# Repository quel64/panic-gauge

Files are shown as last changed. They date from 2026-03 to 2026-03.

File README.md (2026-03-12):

# VIX Fear Gauge Terminal
> **Project Stasis (Tier 2)** | A real-time market volatility monitor.

This project is a dedicated hardware terminal that fetches the **VIX (Volatility Index)** via the Alpha Vantage API and renders a dynamic intraday graph on a 3.2" TFT display.
I made this project because having the value of this index I think is of great importance right now because of the recent conflicts of the world. This terminal allows you to have this "fear gauge" always close to you so if it spikes you know that something big is happening.




## Features
- **Live Tracking:** Real-time updates via Wi-Fi.
- **Dynamic Scaling:** The graph auto-zooms to show movement even during low volatility.
- **Dual Themes:** Swap between Dark Mode and Light Mode with a physical button.
- **Timeframe Toggle:** Switch between 1-minute and 5-minute data resolution.

## Setup & Configuration
1. **Library Install:** Install `TFT_eSPI` and `ArduinoJson` in your Arduino IDE.
2. **Driver Config:** - Navigate to `Arduino/libraries/TFT_eSPI/User_Setup.h`.
   - Ensure the driver is set to `#define ILI9341_DRIVER`.
   - Set pins: `MOSI: 4`, `SCLK: 5`, `CS: 7`, `DC: 6`, `RST: 10`.
3. **API Key:** Get a free key from [Alpha Vantage](https://www.alphavantage.co/support/#api-key).
4. **Firmware:** Open `firmware_vixterminal.ino`, enter your Wi-Fi credentials and API Key, then upload.

## Button Usage
- **Top Button (GPIO 2):** Swaps the data timeframe (1min / 5min).
- **Bottom Button (GPIO 3):** Toggles between Dark and Light UI themes.

## Design
The case features a minimalist **20-degree slant** optimized for desktop viewing. It is 3D-printed in two parts (main body and bottom plate) and requires no screws—the internal components have to be secured via some small drops of adhesive on the backplate.

# Wiring diagram
Component -	Pin	- Connects To

Power -	USB 5V - AMS1117 VIN

Power	- AMS1117 VOUT - ESP32-C3 3.3V & TFT VCC

Power	- GND	- All Common Grounds

Display	- SCK	- ESP32 GPIO 5

Display	- SDI	- ESP32 GPIO 4

Display	- CS	- ESP32 GPIO 7

Display	- DC	- ESP32 GPIO 6

Display	- RST	- ESP32 GPIO 10

Button - 1 - ESP32 GPIO 2 (Timeframe)

Button - 2 - ESP32 GPIO 3 (Theme)

# Project Bill of Materials (BOM)
| Component | Description | Price | Source |
| :--- | :--- | :--- | :--- |
| **ESP32-C3** | Main MCU (SuperMini) | $2.04 | [Link](https://shorturl.at/nSwdf) |
| **3.2" SPI TFT LCD** | ILI9341 Display | $9.32 | [Link](https://shorturl.at/U1MPf) |
| **Solderable Perfboard** | 4x6cm Prototyping Board | $2.19 | [Link](https://shorturl.at/WMAwI) |
| **AMS1117-3.3V** | Voltage Regulator | $1.26 | [Link](https://shorturl.at/bQWA9) |
| **Rubber Feet** | For bottom of the case | $1.71 | [Link](https://shorturl.at/vf0jC) |
| **10uF Capacitors** | Power stabilization | $2.63 | [Link](https://shorturl.at/ITGra) |
| **Tactile Buttons** | 6x6x5mm (Time/Theme) | $0.00 | (In stock) |
| **Resistor Kit** | 10k Ohm pull-ups | $0.00 | (In stock) |
| **TOTAL** | | **$19.15** | |

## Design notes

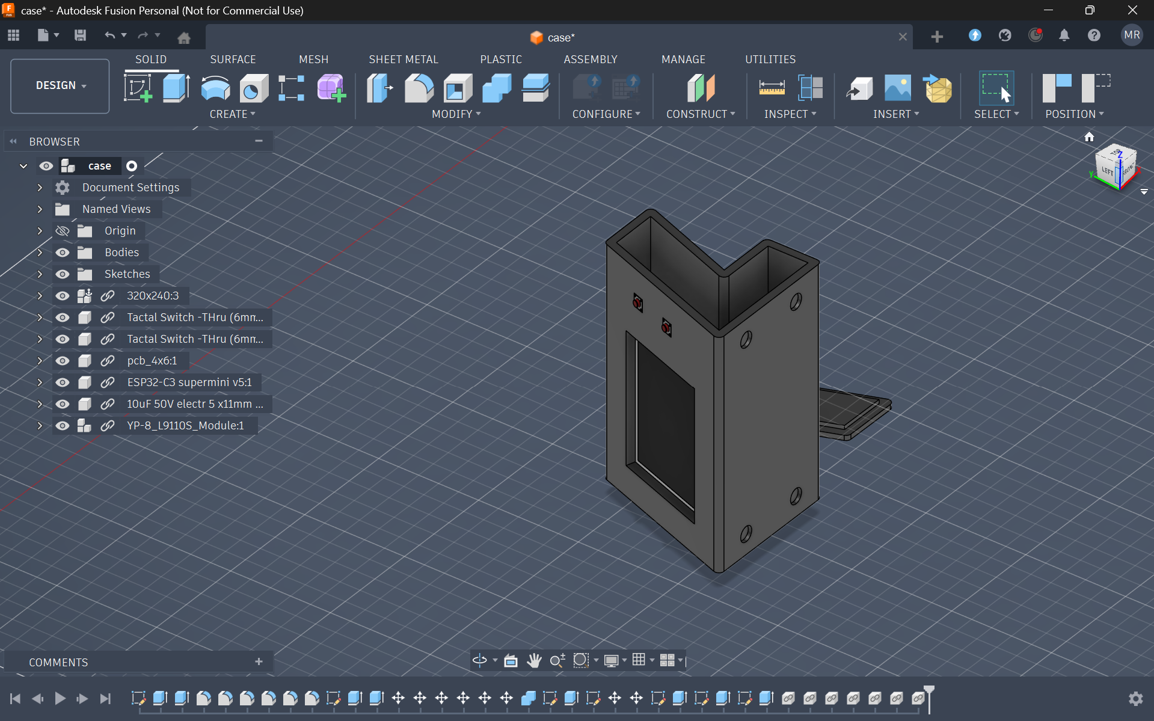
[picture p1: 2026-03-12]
CAD/Screenshot 2026-03-12 140706.png

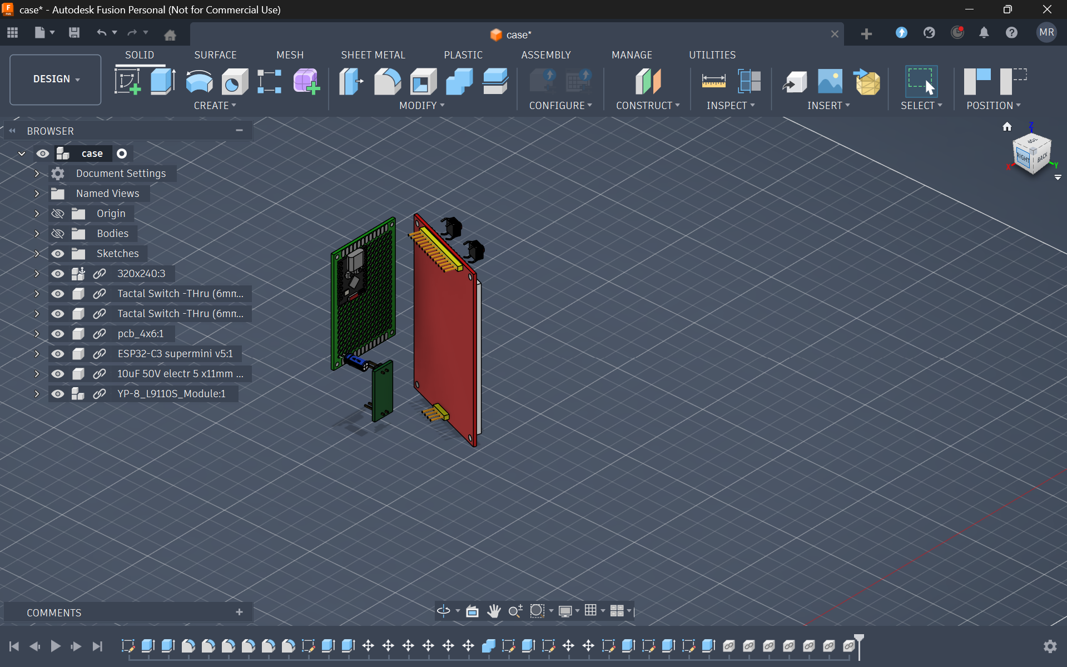
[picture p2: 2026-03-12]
CAD/Screenshot 2026-03-12 140719.png

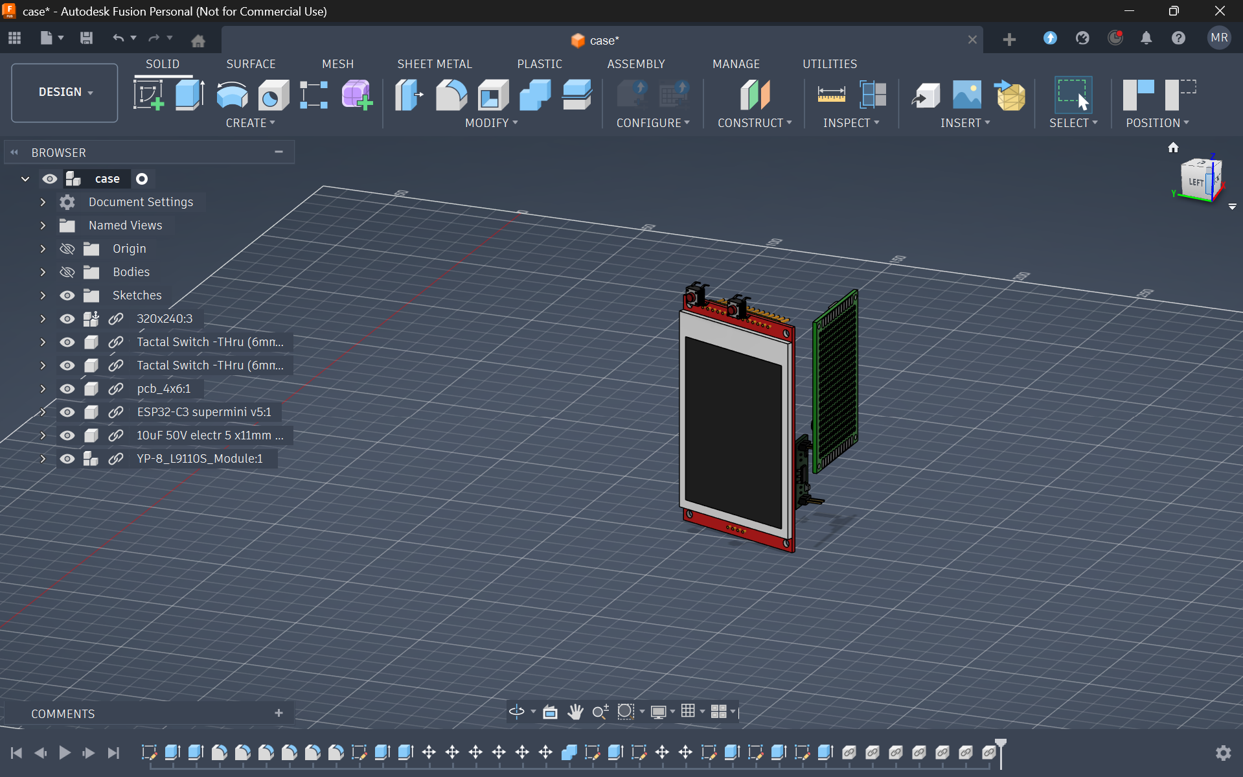
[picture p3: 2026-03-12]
CAD/Screenshot 2026-03-12 140726.png

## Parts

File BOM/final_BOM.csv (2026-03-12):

Full BOM
-Esp32-C3 - $2.04 - https://shorturl.at/nSwdf
-3.2 SPI TFT LCD (ILI9341) - $9.32 - https://shorturl.at/U1MPf
-Solderable Perfboard 4x6cm - $2.19 - https://shorturl.at/WMAwI
-AMS1117-3.3V,Voltage Regulator - $1.26 - https://shorturl.at/bQWA9
-Rubber feet - $1.71 - https://shorturl.at/vf0jC
-10uF capacitors - $2.63 - https://shorturl.at/ITGra
-Tactile Buttons,6x6x5mm - $0
-Resistor Kit 10k - $0
TOTAL: $19.15

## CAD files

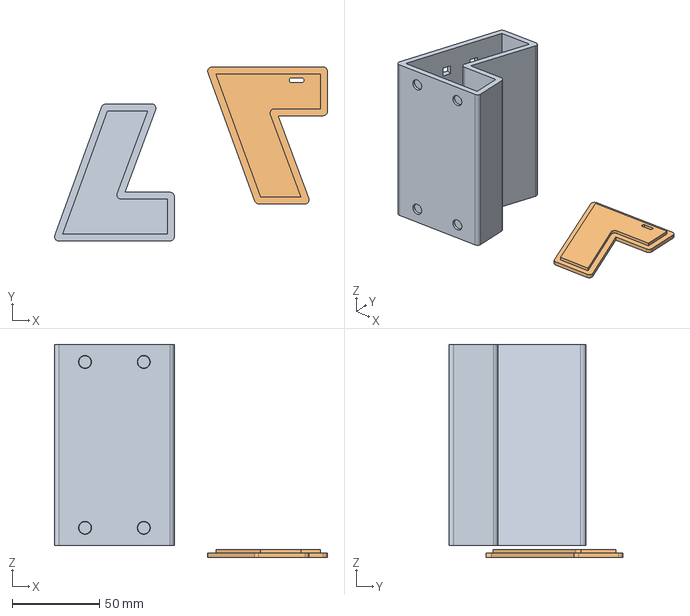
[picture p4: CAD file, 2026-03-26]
CAD/case_only.step
156.4 x 99.8 x 122.0 mm

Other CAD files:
CAD/case+components-.f3z
CAD/case_only.f3d

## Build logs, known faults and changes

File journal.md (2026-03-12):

### Refining the idea and BOM
This project is going to be a compact, real-time small monitor that tracks the VIX index, showing a graph and the current value of the index.

Core Features:
It will be powered by an ESP32-C3, to make it compact but still powerful enough to get the value for the index by an API key.
The graph and value will be shown by a 3.2" SPI display.

Tech Stack:
ESP32-C3
3.2" ILI9341 TFT (SPI)
C++/Arduino with TFT_eSPI for hardware-accelerated rendering.
3D-printed case designed in fusion 360.



### Making the full bom and planing the prices
I have decided not to make a pcb for this project, because it would over-complicate it and i feel like it isn't needed for this simple one.

Full BOM:
Esp32-C3 - $2.04
3.2 SPI TFT LCD (ILI9341) - $9.32
Solderable Perfboard - $2.19
AMS1117-3.3V,Voltage Regulator - $1.26
TOTAL: $14.81


### Designing the case
the design proces for the case was pretty straight foward. The part that tool the longest was to define the actual dimensions of the case, and ake everything fit inside. I have decided on these:



instead of screwing the cover down, i decided that its best to have this case with the small extrusion to secure it, and then when the electronics are all good, glue it to the rest of the case.
then i added the usb-c hole to power everything:


and also some small holes to add some optional rubber feet so it doesnt slide:

now that i finished the CAD, i only have the coding part left.

### setting up tft_espi and the driver config
the biggest pain so far has been the tft_espi library because it doesn't let you define pins in the sketch. you have to go into the library folders and edit User_Setup.h manually.

i spent most of the time cross-referencing the esp32-c3 supermini pinout with the ili9341 datasheet. since the supermini is so small, the pin labels are different than a standard devkit. i decided to use gpio 4, 5, 6, 7 and 10 for the spi bus. it’s a bit of a "blind" setup but i'm pretty sure the mapping is right. i also set the spi frequency to 40mhz so the graph updates look smooth and don't flicker.


### api logic and json
had to pivot the code to use alpha vantage since twelve data wanted money for the vix index. alpha vantage is free but their json is way more nested

coding this blind is tricky because i can't check the serial monitor to see if the json buffer is big enough. i set the DynamicJsonDocument to 8192 bytes just to be safe so it doesn't crash the c3. i also wrote the logic to reverse the data array, because the api sends the newest price first, but the graph needs to draw from left to right (oldest to newest). it took a while to get the loop right so the current price always ends up at the very edge of the screen.


### graph math and finishing the logic
finished the main graphing function today. the vix usually stays in a small range, so if i used a static scale the graph would just look like a flat line. i wrote a dynamic scaling loop that finds the highest and lowest price in the last 30 points and "zooms" the graph to fit the box.
also added the theme toggle for the second button. it basically just swaps the hex codes for the colors (background and text). since i'm skipping the pcb, i made sure the button pins (gpio 2 and 3) use internal pullups in the code so i don't have to solder extra resistors. the full code is done, now i just need the parts to arrive so i can flash it and see if my math actually works.




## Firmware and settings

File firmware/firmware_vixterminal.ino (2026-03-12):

#include <WiFi.h>
#include <HTTPClient.h>
#include <ArduinoJson.h>
#include <TFT_eSPI.h>
#include <SPI.h>

//Configuration
const char* ssid = "WIFI_SSID";
const char* password = "WIFI_PASSWORD";
const char* apiKey = "API_KEY";

//Pins
#define BTN_TIMEFRAME 2
#define BTN_THEME 3

//Globals
TFT_eSPI tft = TFT_eSPI(); 
const int numPoints = 30; //Number of data points for the graph
float vixData[numPoints];
float currentVix = 0.0;
unsigned long lastUpdate = 0;
const unsigned long updateInterval = 60000; //Fetch every 60 seconds

//State Variables
bool isDarkMode = true;
String timeframe = "1min";

//Colors
#define DARK_BG    TFT_BLACK
#define DARK_TEXT  TFT_WHITE
#define DARK_GRID  0x4208
#define LIGHT_BG   TFT_WHITE
#define LIGHT_TEXT TFT_BLACK
#define LIGHT_GRID 0xBDF7
#define VIX_CALM   TFT_GREEN
#define VIX_WARN   TFT_YELLOW
#define VIX_PANIC  TFT_RED

void setup() {
  Serial.begin(115200);
  
  //Initialize Buttons
  pinMode(BTN_TIMEFRAME, INPUT_PULLUP);
  pinMode(BTN_THEME, INPUT_PULLUP);

  //Initialize Screen
  tft.init();
  tft.setRotation(1);
  tft.fillScreen(DARK_BG);

  //Draw Boot Screen
  tft.setTextColor(TFT_WHITE);
  tft.setCursor(50, 100, 4);
  tft.print("Booting VIX Terminal...");

  //Connect to WiFi
  WiFi.begin(ssid, password);
  tft.setCursor(50, 130, 2);
  tft.print("Connecting to WiFi");
  while (WiFi.status() != WL_CONNECTED) {
    delay(500);
    tft.print(".");
    Serial.print(".");
  }
  
  //Initial Fetch & Draw
  tft.fillScreen(isDarkMode ? DARK_BG : LIGHT_BG);
  drawStaticUI();
  fetchVIXData();
}

void loop() {
  //1. Handle Timeframe Button (Pin 2)
  if (digitalRead(BTN_TIMEFRAME) == LOW) {
    delay(200);
    timeframe = (timeframe == "1min") ? "5min" : "1min";
    tft.fillScreen(isDarkMode ? DARK_BG : LIGHT_BG);
    drawStaticUI();
    fetchVIXData();
  }

  //2. Handle Theme Button (Pin 3)
  if (digitalRead(BTN_THEME) == LOW) {
    delay(200);
    isDarkMode = !isDarkMode;
    tft.fillScreen(isDarkMode ? DARK_BG : LIGHT_BG);
    drawStaticUI();
    drawGraph();
    updateStatusText();
  }

  //3. Auto-update data every 60 seconds
  if (millis() - lastUpdate >= updateInterval) {
    fetchVIXData();
    lastUpdate = millis();
  }
}

//Fetch Data from API
void fetchVIXData() {
  if (WiFi.status() == WL_CONNECTED) {
    HTTPClient http;
    //Alpha Vantage URL
    String url = "https://www.alphavantage.co/query?function=TIME_SERIES_INTRADAY&symbol=VIX&interval=5min&apikey=" + String(apiKey);
    
    http.begin(url);
    int httpCode = http.GET();

    if (httpCode == HTTP_CODE_OK) {
      String payload = http.getString();
      
      DynamicJsonDocument doc(8192);
      DeserializationError error = deserializeJson(doc, payload);
      
      if (!error) {
        JsonObject timeSeries = doc["Time Series (5min)"];
        int index = numPoints - 1;
        
        int count = 0;
        for (JsonPair kv : timeSeries) {
          if (count < numPoints) {
            vixData[index] = kv.value()["4. close"].as<float>();
            if (count == 0) currentVix = vixData[index];
            index--;
            count++;
          }
        }
        
        drawGraph();
        updateStatusText();
      }
    }
    http.end();
  }
}

//Draw the UI
void drawStaticUI() {
  uint16_t bg = isDarkMode ? DARK_BG : LIGHT_BG;
  uint16_t text = isDarkMode ? DARK_TEXT : LIGHT_TEXT;
  uint16_t grid = isDarkMode ? DARK_GRID : LIGHT_GRID;

  //Header
  tft.setTextColor(text, bg);
  tft.drawString("VIX INDEX", 10, 10, 4);
  
  tft.setTextColor(TFT_DARKGREY, bg);
  tft.drawString("REAL-TIME VOLATILITY (" + timeframe + ")", 10, 40, 2);

  //Graph Border
  tft.drawRect(10, 70, 300, 130, grid);
  
  //Graph Gridlines
  for (int i = 1; i < 4; i++) tft.drawFastHLine(10, 70 + (i * 32), 300, grid);
  for (int i = 1; i < 6; i++) tft.drawFastVLine(10 + (i * 50), 70, 130, grid);
}

//Render the Graph
void drawGraph() {
  uint16_t bg = isDarkMode ? DARK_BG : LIGHT_BG;
  uint16_t grid = isDarkMode ? DARK_GRID : LIGHT_GRID;
  
  //Clear the inside of the graph box to redraw
  tft.fillRect(11, 71, 298, 128, bg);
  
  //Redraw inside gridlines
  for (int i = 1; i < 4; i++) tft.drawFastHLine(11, 70 + (i * 32), 298, grid);
  for (int i = 1; i < 6; i++) tft.drawFastVLine(10 + (i * 50), 71, 128, grid);

  //Find Min and Max for auto-scaling
  float minVix = vixData[0];
  float maxVix = vixData[0];
  for (int i = 1; i < numPoints; i++) {
    if (vixData[i] < minVix) minVix = vixData[i];
    if (vixData[i] > maxVix) maxVix = vixData[i];
  }
  
  //Add 10% padding to top and bottom of graph scaling
  float padding = (maxVix - minVix) * 0.1;
  if (padding == 0) padding = 1.0;
  minVix -= padding;
  maxVix += padding;

  //Determine line color based on latest VIX level
  uint16_t lineColor = VIX_CALM;
  if (currentVix > 20) lineColor = VIX_WARN;
  if (currentVix >= 30) lineColor = VIX_PANIC;

  //Draw the lines connecting the data points
  int graphW = 298;
  int graphH = 128;
  int graphX = 11;
  int graphY = 199;

  for (int i = 0; i < numPoints - 1; i++) {
    int x1 = graphX + (i * (graphW / (numPoints - 1)));
    int x2 = graphX + ((i + 1) * (graphW / (numPoints - 1)));
    
    int y1 = graphY - ((vixData[i] - minVix) / (maxVix - minVix) * graphH);
    int y2 = graphY - ((vixData[i + 1] - minVix) / (maxVix - minVix) * graphH);

    tft.drawLine(x1, y1, x2, y2, lineColor);
    tft.drawLine(x1, y1+1, x2, y2+1, lineColor);
  }
}

//Update Text Labels
void updateStatusText() {
  uint16_t bg = isDarkMode ? DARK_BG : LIGHT_BG;
  
  //Print Big Current Price
  tft.setTextColor(currentVix >= 30 ? VIX_PANIC : (currentVix > 20 ? VIX_WARN : VIX_CALM), bg);
  tft.drawRightString(String(currentVix, 2) + "   ", 310, 10, 6); 

  //Print Status at bottom
  tft.setTextColor(isDarkMode ? DARK_TEXT : LIGHT_TEXT, bg);
  tft.drawString("STATUS: ", 10, 210, 2);
  
  tft.fillRect(70, 210, 150, 20, bg);
  if (currentVix >= 30) {
    tft.setTextColor(VIX_PANIC, bg);
    tft.drawString("EXTREME FEAR", 70, 210, 2);
  } else if (currentVix > 20) {
    tft.setTextColor(VIX_WARN, bg);
    tft.drawString("ELEVATED RISK", 70, 210, 2);
  } else {
    tft.setTextColor(VIX_CALM, bg);
    tft.drawString("MARKET CALM", 70, 210, 2);
  }
}

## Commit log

2026-03-12 Add full BOM with component details and pricing
2026-03-12 Remove markdown header from BOM file
2026-03-12 Add project overview and technical details to journal
    Documented project details including features, BOM, case design, TFT setup, API logic, and graphing logic.
2026-03-12 Update and rename final_BOM.cvs to final_BOM.csv
    [final_BOM.csv]
2026-03-12 Add wiring diagram to README
    Added wiring diagram for ESP32-C3 and TFT display connections.
2026-03-12 Revise prices and total in final BOM
    Updated component prices and total in BOM.
    [final_BOM.csv]
2026-03-12 Add Project Bill of Materials to README
    Added a Project Bill of Materials (BOM) section with components, descriptions, prices, and sources.
